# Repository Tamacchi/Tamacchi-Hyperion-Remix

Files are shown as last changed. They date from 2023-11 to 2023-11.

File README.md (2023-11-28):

# Tamacchi Modified Hyperion Case and Lupinix PCB for SlimeVR

## Use caution for USB C Aux ports. The IMUs are not 5V compatible and will damage IMUs if plugged into other devices.

You may place an order with me on Discord for these boards. Add me! 
My username is "tamacchi".

Join SlimeVR Discord: https://discord.gg/slimevr

Check out my marketplace listing: https://discord.com/channels/817184208525983775/1149939588639502406

### Parts
Uses 4-pin USB C Breakout Board for Aux: https://www.aliexpress.com/item/1005005187670446.html

WEMOS D1 Mini MicroUSB

SS12D00G3 (Switch)

TP4056

25MM and 40MM Straps

1N5817 Diode (2x)

180K Ohm Resistor

804040 Batteries

### Electronics

Uses 1800mAh 804040 batteries, but can fit 804050 or 805040 batteries.

Requires you to manually wire 4 cables from the AUX pins to a USB C breakout board.

You must add at least 5 layers of paper tape between the USB C breakout board and the TP4056 beneath. Otherwise, it may contact the TP4056 below. 

Requires you to clip the sides of the USB C breakout board to fit into the printed notches. Then, add 3M tape on the empty spaces above the breakout board on the main case to minimize movement.

The TP4056 and Aux Case side of the USB C breakout board should be soldered directly onto the board without header pins.

The 3rd leg of the switch needs to be cut off to fit into the tray. 

### 3D Printing
You may choose to print the Shielding STL that goes under the USB C breakout board. Use 3M to tape it under the USB C breakout board to hold it in place. It will separate the distance between TP4056 and the USB C breakout board. PLA is not advised for this print, as it is located close to the TP4056 board which can generate a lot of heat. Please use high-temperature filaments such as PETG, ABS, or ASA.

The Forward Tray version pushes the TP4056's USB C port forward more, making it look neater and sit nicely in the printed USB C port hole.

Dual Color Printing stl files have a small 0.03mm indent on the top of the lid for the symbols and text. This allows you to separate them from the rest of the lid while printing everything on  the first layer when coloring in using Bambu Lab's color fill feature. 

Please rotate lid files with the top of the lid facing down on the bed before printing.

Not compatible with original hyperion.

### Original File Sources

https://github.com/Smeltie/Hyperion

https://github.com/Lupinixx/SlimeVR-Hyperion-BMI160-PCB

I have originally contributed to the 804040 STL variants for the Lupinix PCB. If you would like to use those, please take the STL files from here instead as there were many changes to fix the flaws of the original case design. (Non-aux version)

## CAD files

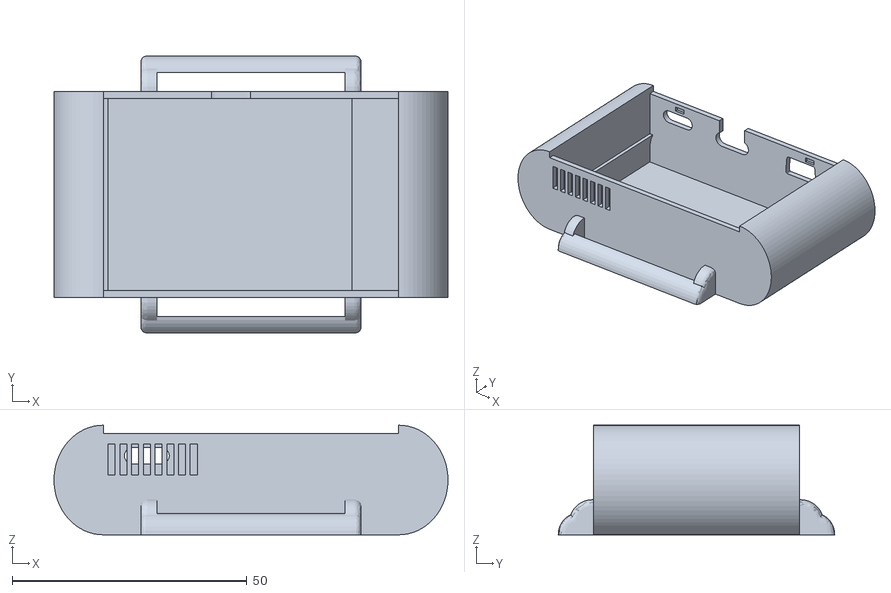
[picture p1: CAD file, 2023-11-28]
STL Prints/Normal Version/Lupinix Main Case.stl
84.0 x 59.0 x 23.4

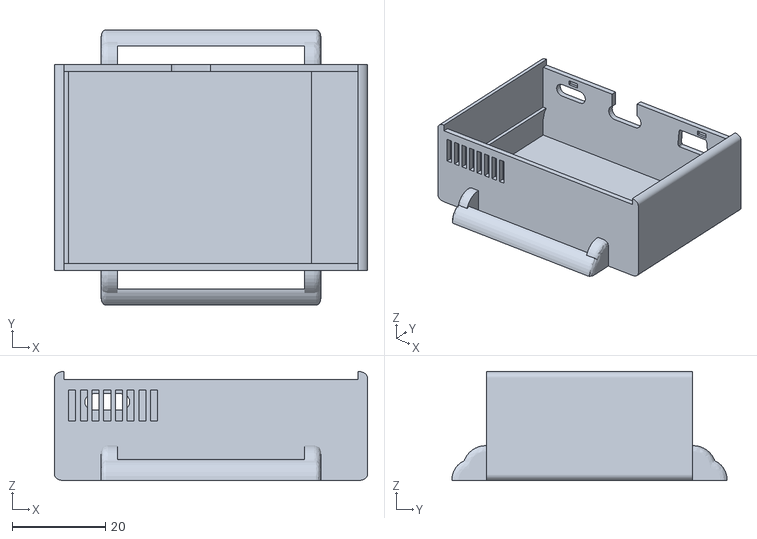
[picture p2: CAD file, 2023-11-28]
STL Prints/Compact Version/Lupinix Main Case (Compact).stl
67.0 x 59.0 x 23.4

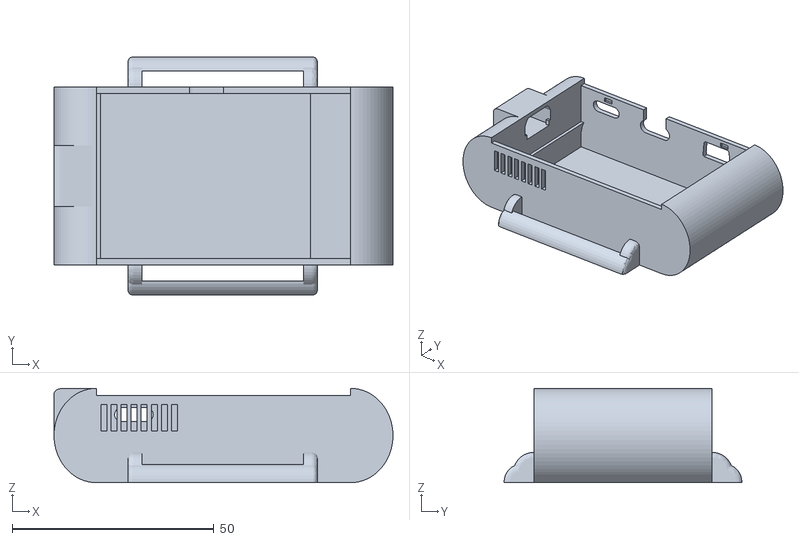
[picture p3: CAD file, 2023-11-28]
STL Prints/Normal Version/Lupinix Main Case with Aux Port.stl
84.0 x 59.0 x 23.4

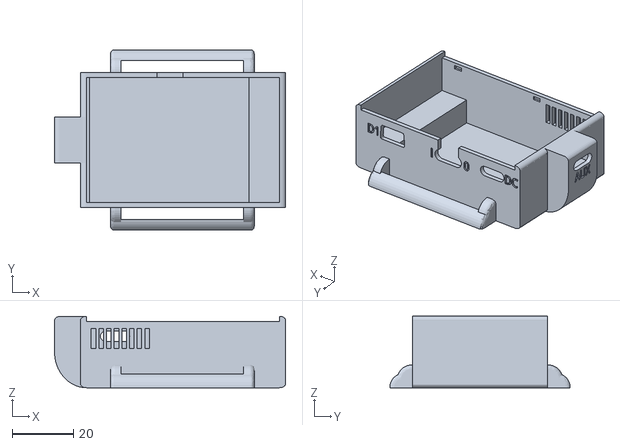
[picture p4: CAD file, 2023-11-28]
STL Prints/Compact Version/Lupinix Main Case with Aux Port (Compact).stl
75.5 x 59.0 x 23.4

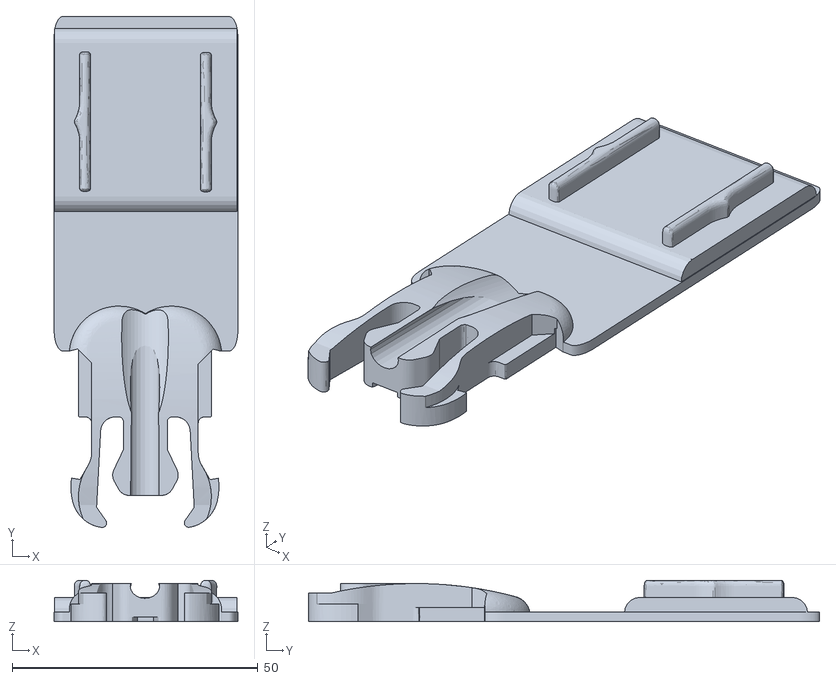
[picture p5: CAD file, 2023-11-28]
STL Prints/Compact Version/Chest Harness Clip (Compact).stl
37.4 x 104.0 x 8.44

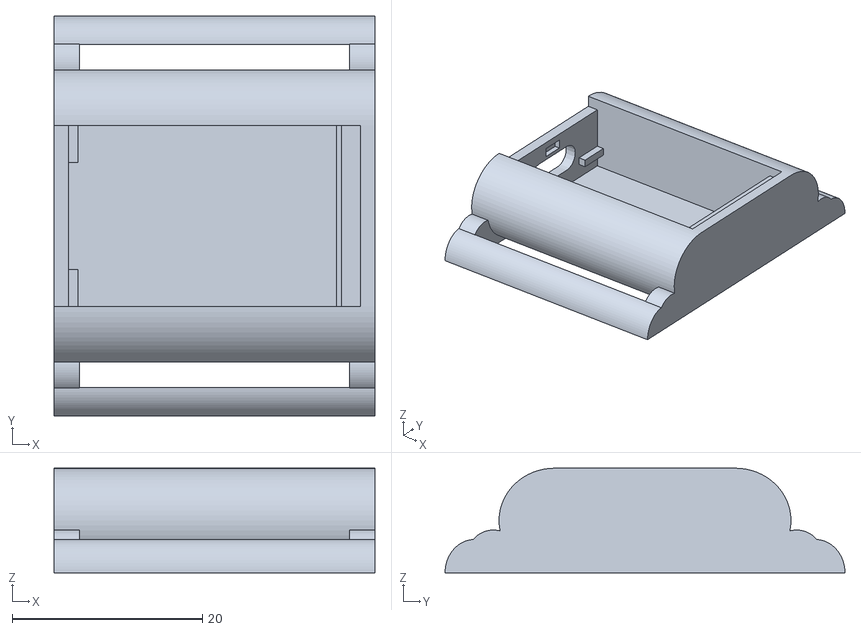
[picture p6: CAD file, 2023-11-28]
STL Prints/Normal Version/25mm Aux Case for PCB.stl
33.7 x 42.0 x 11.0

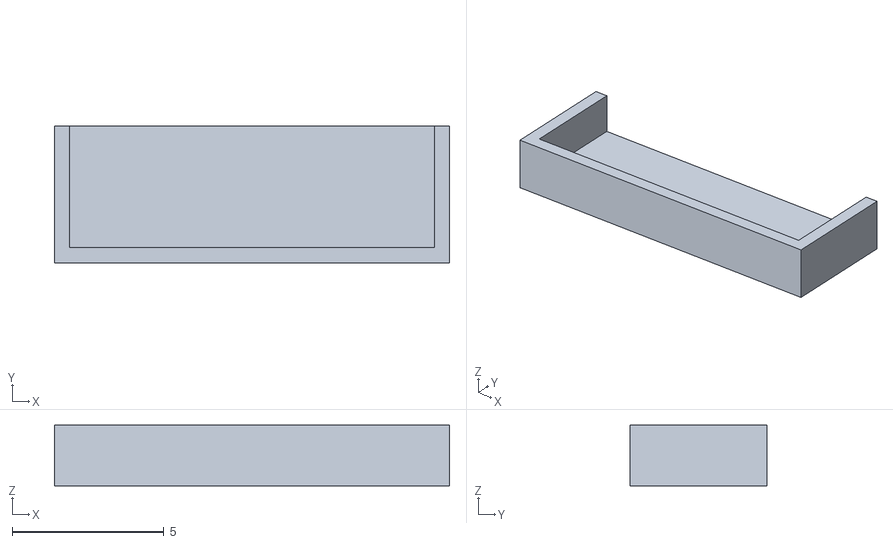
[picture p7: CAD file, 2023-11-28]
STL Prints/TP4056 - USB C Shielding.stl
13.0 x 4.50 x 2.00

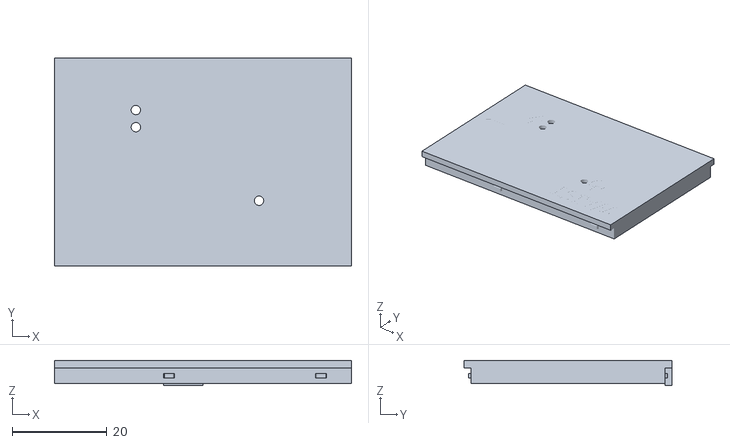
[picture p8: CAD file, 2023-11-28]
STL Prints/Universal Lid/Dual Color Print (Use Fill)/6. W.stl
62.8 x 44.0 x 5.37

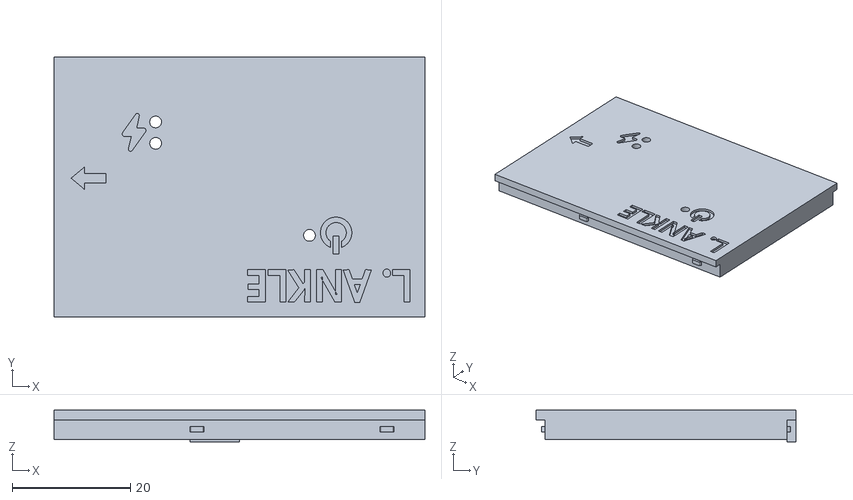
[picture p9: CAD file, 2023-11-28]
STL Prints/Universal Lid/Single Color Print/1. LA.stl
62.8 x 44.0 x 5.37

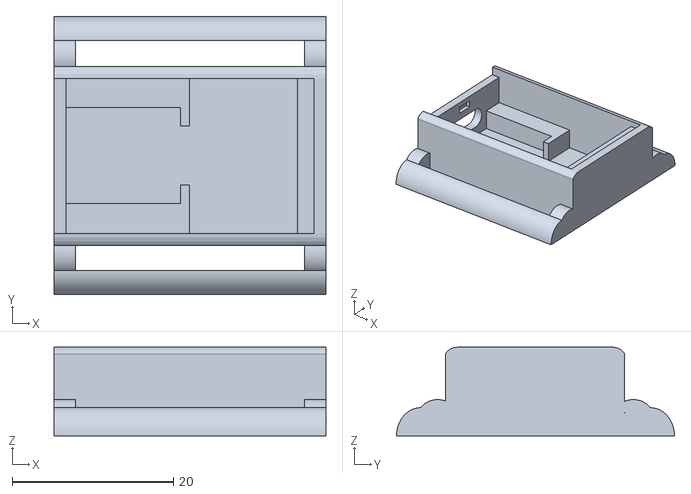
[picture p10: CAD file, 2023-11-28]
STL Prints/Compact Version/25mm Aux Case (Compact).stl
33.7 x 34.5 x 11.0

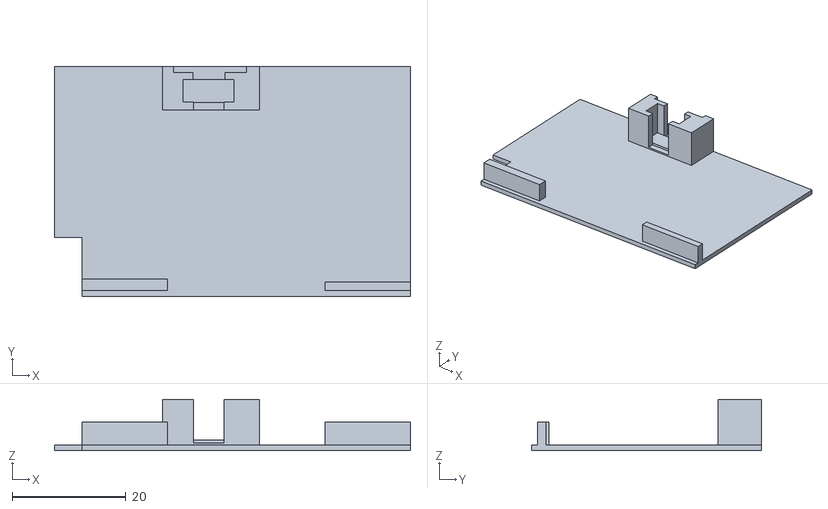
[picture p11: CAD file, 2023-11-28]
STL Prints/Tray Normal.stl
62.5 x 40.3 x 9.00

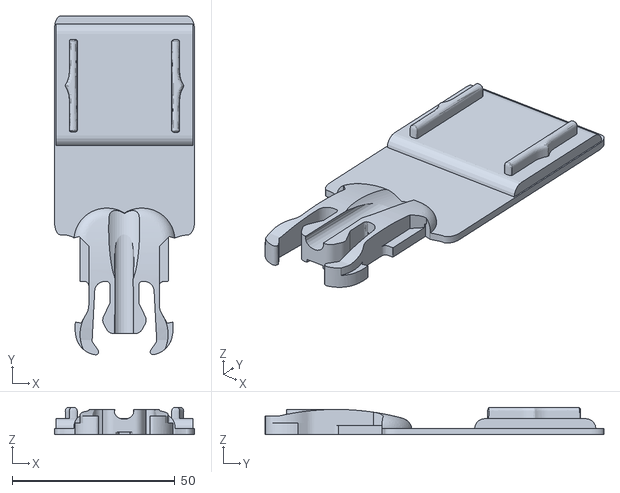
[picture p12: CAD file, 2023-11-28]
STL Prints/Normal Version/Chest Harness Clip.stl
43.0 x 104.0 x 8.44

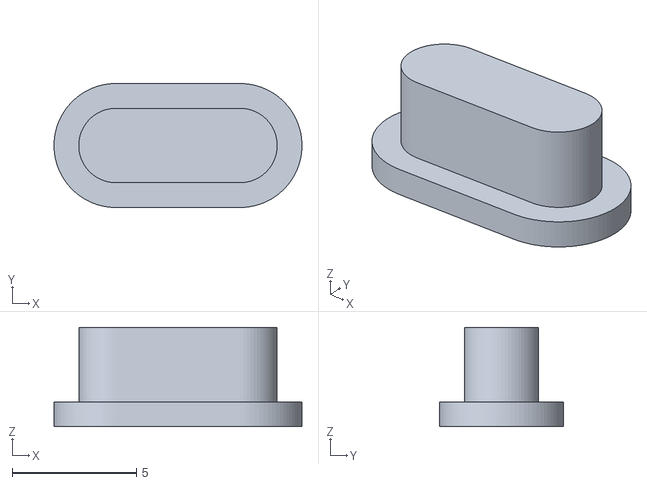
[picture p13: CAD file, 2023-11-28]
STL Prints/Switch.stl
10.00 x 5.00 x 4.00

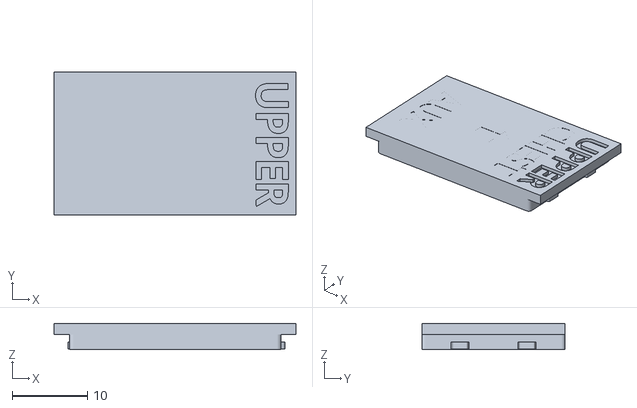
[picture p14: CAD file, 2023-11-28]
STL Prints/Universal Lid/Dual Color Print (Use Fill)/12. Upper Chest.stl
32.2 x 19.1 x 3.49

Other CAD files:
STL Prints/Universal Lid/Dual Color Print (Use Fill)/7. LE.stl
STL Prints/Universal Lid/Single Color Print/4. RT.stl
STL Prints/Universal Lid/Single Color Print/7. LE.stl
STL Prints/Compact Version/25mm Aux Case for PCB (Compact).stl
STL Prints/Normal Version/25mm Aux Case.stl
STL Prints/Tray USB C Forward.stl
STL Prints/Universal Lid/Dual Color Print (Use Fill)/1. LA.stl
STL Prints/Universal Lid/Dual Color Print (Use Fill)/10. R. Foot.stl
STL Prints/Universal Lid/Dual Color Print (Use Fill)/11. Chest.stl
STL Prints/Universal Lid/Dual Color Print (Use Fill)/2. RA.stl
STL Prints/Universal Lid/Dual Color Print (Use Fill)/3. LT.stl
STL Prints/Universal Lid/Dual Color Print (Use Fill)/4. RT.stl
STL Prints/Universal Lid/Dual Color Print (Use Fill)/5. Hip.stl
STL Prints/Universal Lid/Dual Color Print (Use Fill)/8. RE.stl
STL Prints/Universal Lid/Dual Color Print (Use Fill)/9. L. Foot.stl
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
